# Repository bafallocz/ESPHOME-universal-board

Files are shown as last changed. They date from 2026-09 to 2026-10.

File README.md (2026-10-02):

# ESPHOME-universal-board

Modular, multi-purpose automation control boards designed around the **Seeed Studio XIAO** form-factor (ESP32-C3 / S3 / RP2040), tailored for **ESPHome**, **Home Assistant**, and standalone embedded automation projects.

The system consists of three hardware revisions/modules:
1. **Universal Board (Full Version)** – High-density I/O, mains-powered, precision analog/PWM expansion, gate-driven power MOSFETs, and relays.
2. **Universal Board (Light Version)** – Compact DC-powered board with direct logic-level SMD MOSFETs, relays, and inputs.
3. **Relay Expansion Board (Stackable)** – Dedicated 5-channel relay daughterboard controlled via the Full version's I2C PWM expander.

---

## Hardware Overview & Specifications

### 1. Board One: Full Version (Flagship)

Designed as a central automation node capable of direct 230 V mains operation, multi-channel high-current PWM control, mixed-signal ADC/DAC sensing, and galvanic isolation.

* **Core MCU:** Socket for Seeed Studio XIAO module (ESP32-C3, ESP32-S3, etc.).
* **Power Supply Options:**
  * **Mains AC Input:** Onboard **Hi-Link HLK-20M12** (20 W, 12 V / 1.66 A) isolated AC/DC power supply.
  * **Mains Protection:** 10D561K Metal Oxide Varistor (MOV) for surge and transient suppression.
  * **DC Input:** 2.1 mm DC Barrel Jack (`PJ-102AH`) for external 12 V DC supply.
  * **Step-Down:** Footprint for LM7805 LDO or pin-compatible high-efficiency DC-DC switching buck regulator (12 V to 5 V).
* **Power Outputs (4x High-Current PWM):**
  * **MOSFETs:** TO-220 footprint (tested with **IRL540N** / **IRFB4110PBF**).
  * **Gate Drivers:** Dual high-speed drivers (**TC4427** running at 12 V rail). Delivers up to 1.5 A peak gate drive current for fast switching transitions and minimal thermal loss during high-frequency PWM.
  * **Ratings:** Up to 60 V DC, 10 A burst / 5 A continuous per channel (dependent on PCB copper weight and heatsinking).
* **Analog & Precision I/O:**
  * **Analog Devices AD5593R** (12-bit, 8-channel configurable ADC / DAC / GPIO via I2C).
  * Onboard 2.5 V low-drift reference (`VREF`), filtered analog supplies, and dedicated 8-pin terminal/pin header.
* **Expanded PWM:**
  * **NXP PCA9685PW** (16-channel, 12-bit I2C PWM controller).
  * Channel `LED0` can be routed to high-current output/dimming, remaining channels (`EX_PWM1`–`EX_PWM15`) routed to stack header `JP1`.
* **Relays (2x Isolated):**
  * **Songle SRD-05VDC-SL-C** SPDT relays (rated 250 VAC / 10 A, 30 VDC / 10 A).
  * **Isolation & Drive:** Opto-isolated via **CPC1018N** 1-Form-A Solid State Relays (SSR) to isolate MCU logic from inductive switching spikes.
  * Flyback protection diodes on each coil.
* **Digital Inputs (2x Terminals):**
  * Dedicated screw terminals with 1k series current limiting.
  * **Nexperia PESD3V3L2BT** TVS/ESD diode array for surge/ESD protection on 3.3 V logic.
* **Expansion:** All unused XIAO GPIOs routed to standard 2.54 mm pin headers (`PHD1`, `PHD2`).

---

### 2. Board Two: Light Version

A low-profile, cost-optimized DC-powered board ideal for decentralized sub-nodes, LED strip dimming, and valve/motor switching.

* **Core MCU:** Seeed Studio XIAO module footprint.
* **Power Supply:**
  * DC Barrel Jack (`PJ-102AH`) feeding a dedicated pin-compatible DC-DC Step-Down module.
  * USB-C 5 V powering option with selectable `U_SEL` power routing jumper.
* **Power Outputs (3x SMD PWM):**
  * **MOSFETs:** **AO3400A** (N-channel, 30 V / 5.7 A).
  * Driven directly from MCU GPIOs.
  * Ideal for 12 V / 24 V LED strips (up to 3 A continuous per channel without forced cooling).
* **Relays (2x):**
  * 2x **SRD-05VDC-SL-C** driven via **CPC1018N** solid-state optical switches.
* **Digital Inputs (2x):**
  * Terminal block inputs with pull-ups/pull-downs for reed switches, dry contacts, or external buttons.
* **Expansion:** Unused pins broken out to side headers for I2C or SPI sensors.

---

### 3. Board Three: Expansion Board (Stackable)

An add-on hat designed to mount directly onto the **Full Version** via headers `PHD1`, `PHD2`, and `JP1`.

* **5x Additional Relays:** **SRD-05VDC-SL-C** (230 VAC / 10 A contact rating).
* **Control Bus:** Driven directly by the Full Board’s **PCA9685** PWM/GPIO expander (`EX_PWM1` through `EX_PWM5`).
* **Isolation:** Each relay coil is switched through an independent **CPC1018N** optical isolation relay.
* **Pass-through Routing:**
  * Leaves `EX_PWM6`–`EX_PWM15` available for additional servo or PWM peripherals.
  * Passes through AD5593R DAC/ADC lines and spare MCU GPIOs.

---

## Hardware Operating Limits & Safety Guidelines

> [!WARNING]
> **Mains Voltage Hazard:** The Full Version contains exposed 230 VAC tracks. Always install in an insulated DIN-rail or 3D-printed enclosure (**FR MATERIAL**). Maintain appropriate creepage and clearance distances between mains tracks and low-voltage logic.

* **Relay Contacts:** Rated for 10 A @ 250 VAC resistive load. For inductive loads (motors, pumps, contactors).
* **Full Board PWM Channels:** While the MOSFETs (IRFB4110 / IRL540N) have high silicon current ratings.
* **Light Board PWM Channels:** AO3400A is rated for 5.7 A peak; recommended continuous load per channel is **2.5 A to 3 A** without a copper heatsink pour.
* **Power Supply Headroom:** The HLK-20M12 provides up to 1.66 A at 12 V. When running multiple relays and external 12 V loads simultaneously, verify total DC power consumption remains under 20 W.

---

## AD5593R ESPHome Component

This repository includes a custom ESPHome component for the **Analog Devices AD5593R** (8-channel 12-bit configurable ADC / DAC / GPIO).

### How to Import into ESPHome

Add the `external_components` block to your YAML configuration:

#### Option A: Direct from GitHub
```yaml
external_components:
  - source: github://bafallocz/ESPHOME-universal-board
    components: [ ad5593r ]
```

#### Option B: Local Component (when compiling inside this repo)
```yaml
external_components:
  - source: components
    components: [ ad5593r ]
```

---

### AD5593R Configuration Guide

Any of the 8 pins (`0` to `7`) can be independently configured as an **ADC input**, **DAC output**, **Digital input (`binary_sensor`)**, or **Digital output (`switch`)**.

#### 1. Hub Definition
```yaml
ad5593r:
  - id: ad5593r_hub
    i2c_id: bus_a
    address: 0x10
    # reference_voltage: 2.5V  # Internal reference (default 2.5V)
    # gain_2x: true            # Default true -> Full range 0 to 5.0 V
```

#### 2. Analog Outputs (DAC) - Channels 0 to 7
Outputs range from `0.0` (0 V) to `1.0` (5.0 V):
```yaml
output:
  - platform: ad5593r
    ad5593r_id: ad5593r_hub
    channel: 0
    id: dac_out_0

  - platform: ad5593r
    ad5593r_id: ad5593r_hub
    channel: 1
    id: dac_out_1
```

Control DAC outputs using a Home Assistant template slider:
```yaml
number:
  - platform: template
    name: "DAC 0 Output"
    min_value: 0
    max_value: 1
    step: 0.01
    mode: slider
    set_action:
      - output.set_level:
          id: dac_out_0
          level: !lambda 'return x;'
```

#### 3. Analog Inputs (ADC) & Internal Temperature Sensor
Reports voltage values in **Volts (V)**:
```yaml
sensor:
  - platform: ad5593r
    ad5593r_id: ad5593r_hub
    channel: 2
    name: "AD5593R Analog Input 2"
    update_interval: 1s

  - platform: ad5593r
    ad5593r_id: ad5593r_hub
    channel: 3
    name: "AD5593R Analog Input 3"
    update_interval: 1s

  # Chip Internal Temperature Sensor (°C)
  - platform: ad5593r
    ad5593r_id: ad5593r_hub
    channel: temperature
    name: "AD5593R Internal Temperature"
    update_interval: 10s
```

#### 4. Digital Inputs (`binary_sensor`)
Reads logic state from pins (with optional 85 kΩ internal pull-down):
```yaml
binary_sensor:
  - platform: ad5593r
    ad5593r_id: ad5593r_hub
    channel: 4
    name: "AD5593R Digital Input 4"
    pulldown: true
```

#### 5. Digital Outputs (`switch`)
Controls digital output logic high/low on pins:
```yaml
switch:
  - platform: ad5593r
    ad5593r_id: ad5593r_hub
    channel: 5
    name: "AD5593R Digital Output 5"
```

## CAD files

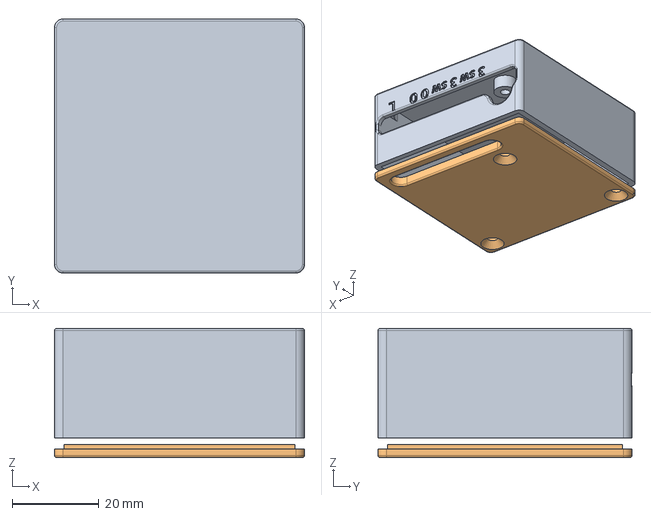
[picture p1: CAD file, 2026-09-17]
LIGH VERSION/esp_home_light_housing.step
57.7 x 58.7 x 29.8 mm

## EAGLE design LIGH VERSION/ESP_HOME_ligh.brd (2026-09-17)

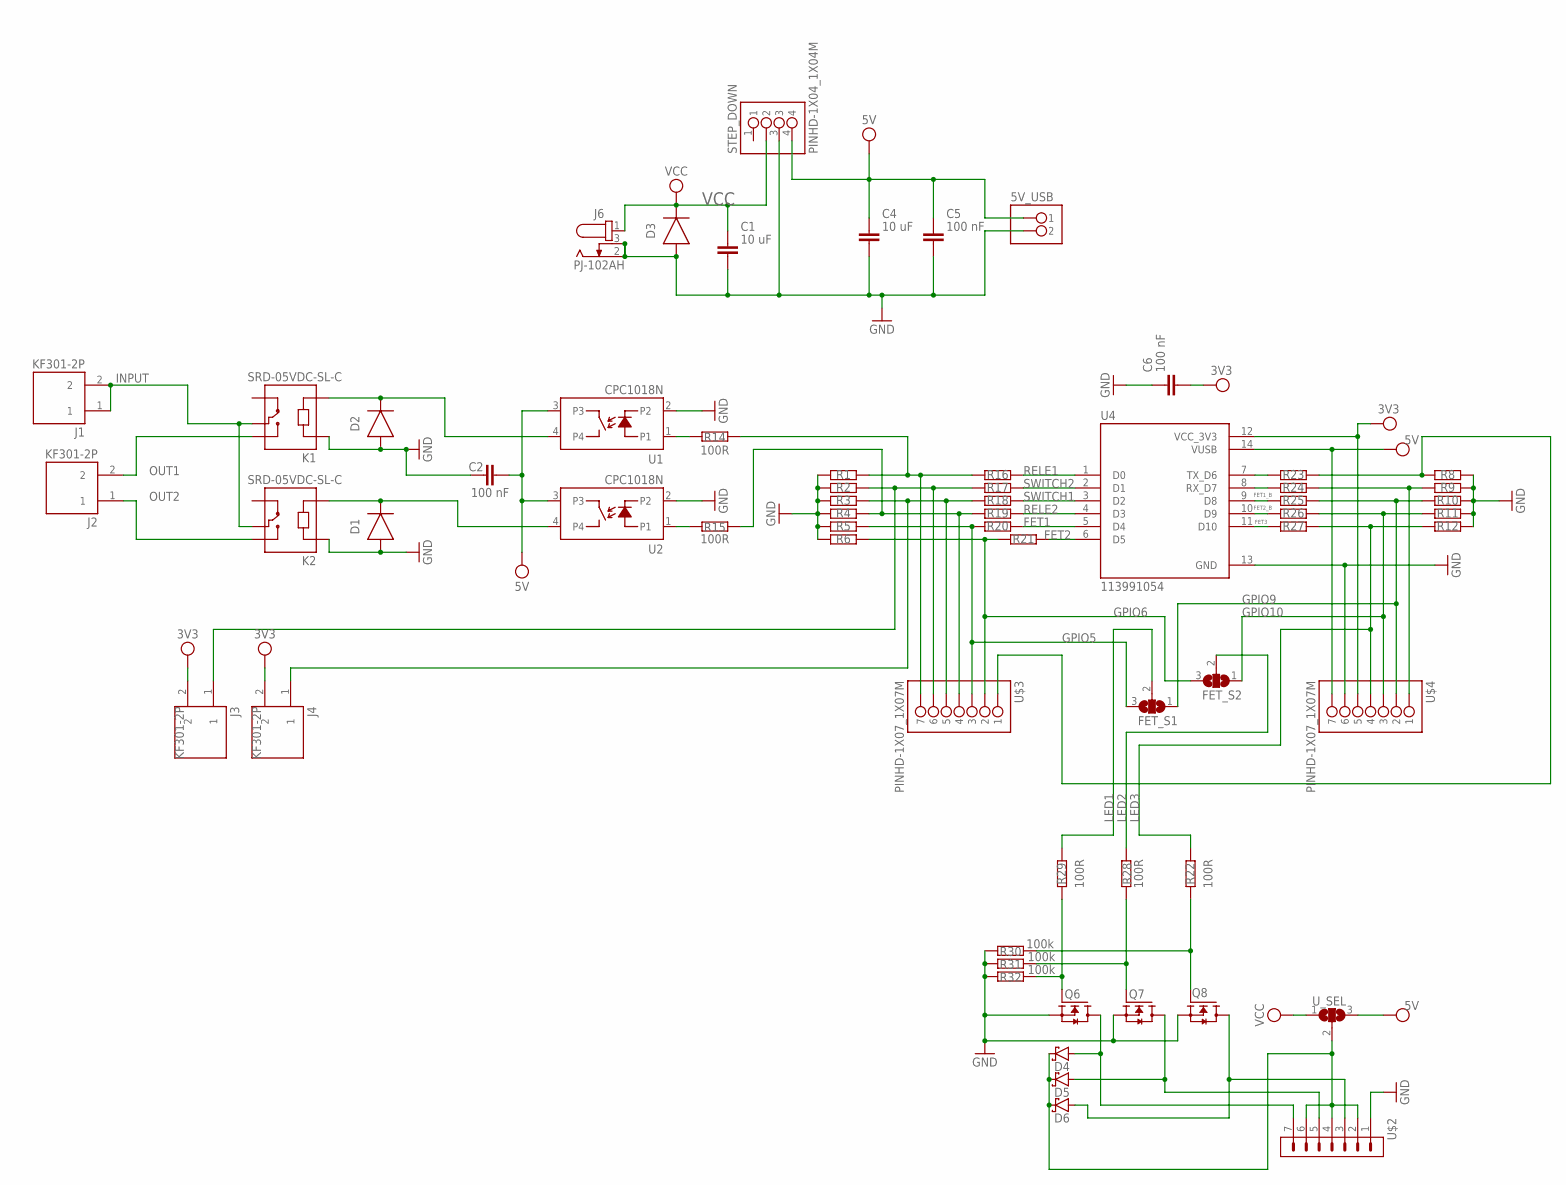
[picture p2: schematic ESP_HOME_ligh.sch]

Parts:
5V_USB: PINHD-1X02_1X02M; 1X02
C1, C4: 10 uF; CAPC2012X110
C2, C5, C6: 100 nF; CAPC2012X110
D1, D2, D3: DIODEDIODE-AXIAL; DIODE-AXIAL
D4, D5, D6: SCHOTTKY_MBR0520LT1GDO-219; SODFL3718X115
FET_S1, FET_S2: SJ2W; SJ_2
J1, J2, J3, J4: KF301-2P; HANDSON_KF301-2P
J6: PJ-102AH
K1, K2: SRD-05VDC-SL-C; RELAY_SRD-05VDC-SL-C
Q6, Q7, Q8: AO3400A; SOT95P280X125-3N
R1, R2, R3, R4, R5, R6, R8, R9, R10, R11, R12, R16, R17, R18, R19, R20, R21, R23, R24, R25, R26, R27: R_CHIP-1206(3216-METRIC); RESC3216X70
R14, R15, R22, R28, R29: 100R; RESC3216X70
R30, R31, R32: 100k; RESC3216X70
STEP_DOWN: PINHD-1X04_1X04M; 1X04
U1, U2: CPC1018N; CLARE_SO4
U4: 113991054; MODULE_113991054
U$2: PINHD-1X7; 1X07
U$3, U$4: PINHD-1X07_1X07M; 1X07
U_SEL: SJ2W; SJ_2

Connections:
3V3: C6.2, J3.2, J4.2, U4.12 (VCC_3V3), U$4.5
5V: 5V_USB.1, C2.2, C4.1, C5.1, STEP_DOWN.4, U1.3, U2.3, U4.14 (VUSB), U$4.7, U_SEL.3
FET1: R20.2, U4.5 (D4)
FET1_B: R25.1, U4.9 (D8)
FET2: R21.2, U4.6 (D5)
FET2_B: R26.1, U4.10 (D9)
FET3: R27.1, U4.11 (D10)
GND: 5V_USB.2, C1.2, C2.1, C4.2, C5.2, C6.1, D1.1 (A), D2.1 (A), D3.1 (A), J6.2, J6.3, K1.A1, K2.A1, Q6.2 (S), Q7.2 (S), Q8.2 (S), R1.1, R2.1, R3.1, R4.1, R5.1, R6.1, R8.2, R9.2, R10.2, R11.2, R12.2, R30.2, R31.2, R32.2, STEP_DOWN.3, U1.2, U2.2, U4.13 (GND), U$2.1, U$4.6
GPIO5: FET_S1.3, R5.2, R20.1, U$3.3
GPIO6: FET_S2.3, R6.2, R21.1, U$3.2
GPIO9: FET_S1.1, R10.1, R25.2, U$4.2
GPIO10: FET_S2.1, R11.1, R26.2, U$4.3
INPUT: J1.1, J1.2, K1.COM, K2.COM
LED1: FET_S1.2, R29.2
LED2: FET_S2.2, R28.1
LED3: R12.1, R22.2, R27.2, U$4.4
unnamed: R14.2, U1.1
unnamed: D4.2 (A), Q6.3 (D), U$2.7
unnamed: R23.1, U4.7 (TX_D6)
unnamed: R24.1, U4.8 (RX_D7)
unnamed: Q6.1 (G), R29.1, R32.1
unnamed: Q7.1 (G), R28.2, R31.1
unnamed: Q8.1 (G), R22.1, R30.1
unnamed: R15.2, U2.1
unnamed: D1.2 (C), K2.A2, U2.4
unnamed: D2.2 (C), K1.A2, U1.4
unnamed: R9.1, R24.2, U$4.1
unnamed: R8.1, R23.2, U$3.1
unnamed: R4.2, R15.1, R19.1, U$3.4
unnamed: D4.1 (C), D5.1 (C), D6.1 (C), U$2.2, U$2.4, U$2.6, U_SEL.2
unnamed: D5.2 (A), Q7.3 (D), U$2.5
unnamed: D6.2 (A), Q8.3 (D), U$2.3
unnamed: R1.2, R14.1, R16.1, U$3.7
OUT1: J2.2, K1.NO
OUT2: J2.1, K2.NO
RELE1: R16.2, U4.1 (D0)
RELE2: R19.2, U4.4 (D3)
SW1: J3.1, R2.2, R17.1, U$3.6
SW2: J4.1, R3.2, R18.1, U$3.5
SWITCH1: R18.2, U4.3 (D2)
SWITCH2: R17.2, U4.2 (D1)
VCC: C1.1, D3.2 (C), J6.1, STEP_DOWN.2, U_SEL.1

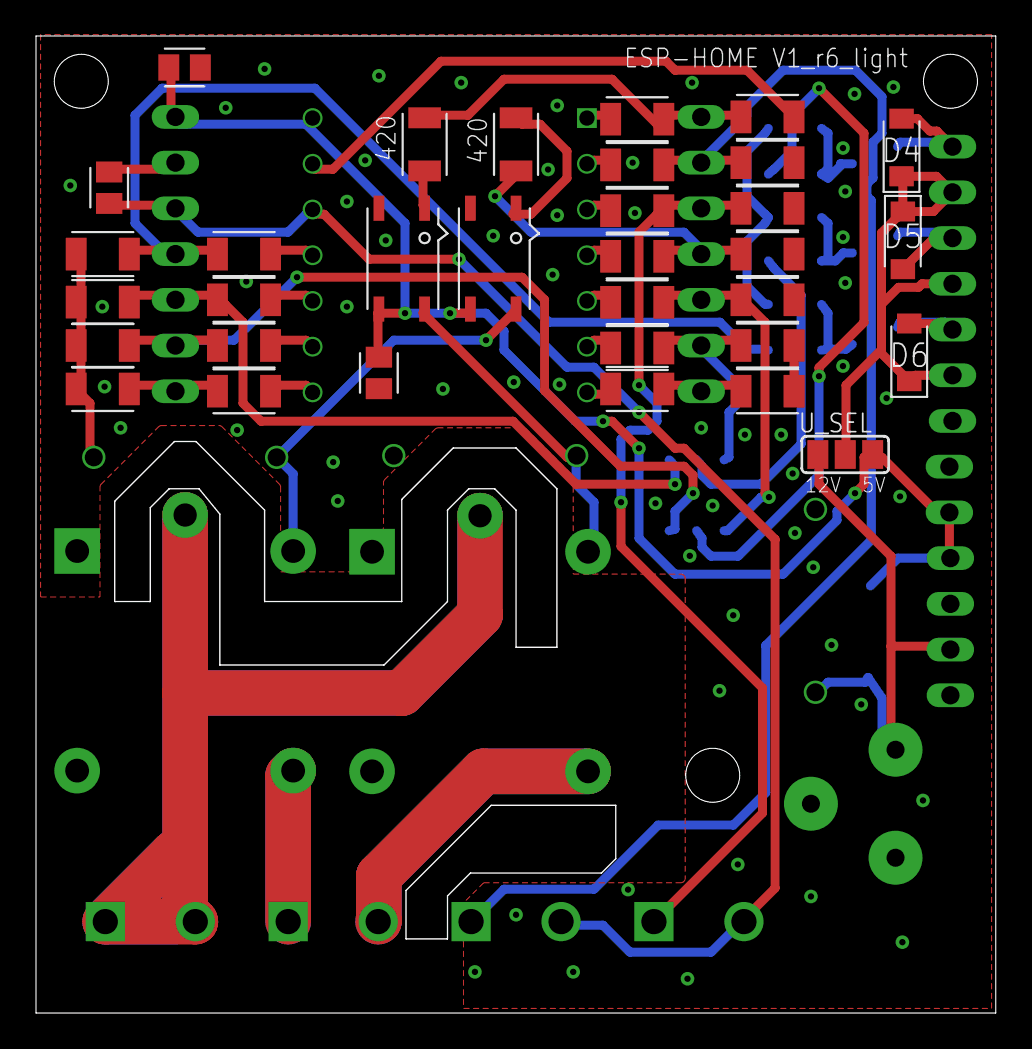
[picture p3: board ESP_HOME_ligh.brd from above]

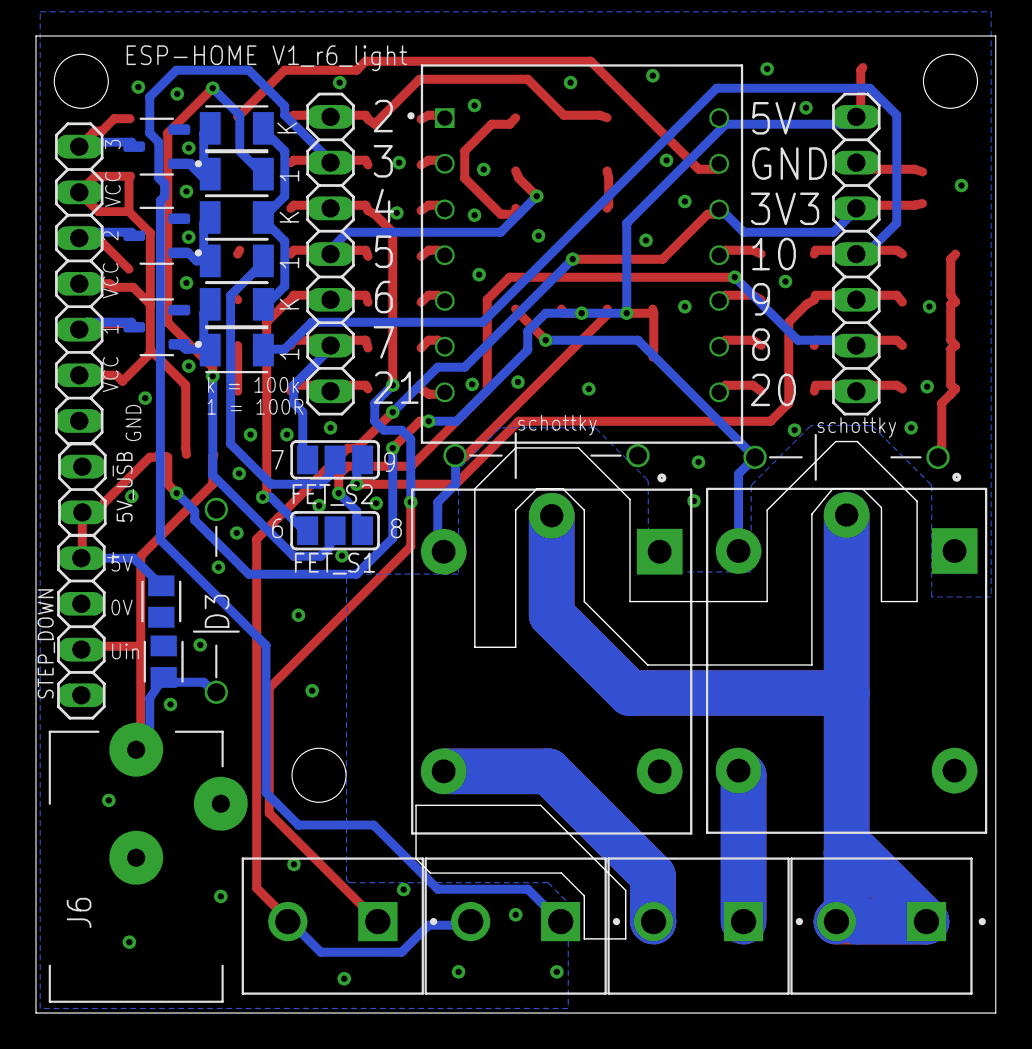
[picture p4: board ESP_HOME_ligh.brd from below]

Board: 2 copper layers, 53.3 x 54.3 mm, 62 parts (29 on the bottom side), 42 nets.

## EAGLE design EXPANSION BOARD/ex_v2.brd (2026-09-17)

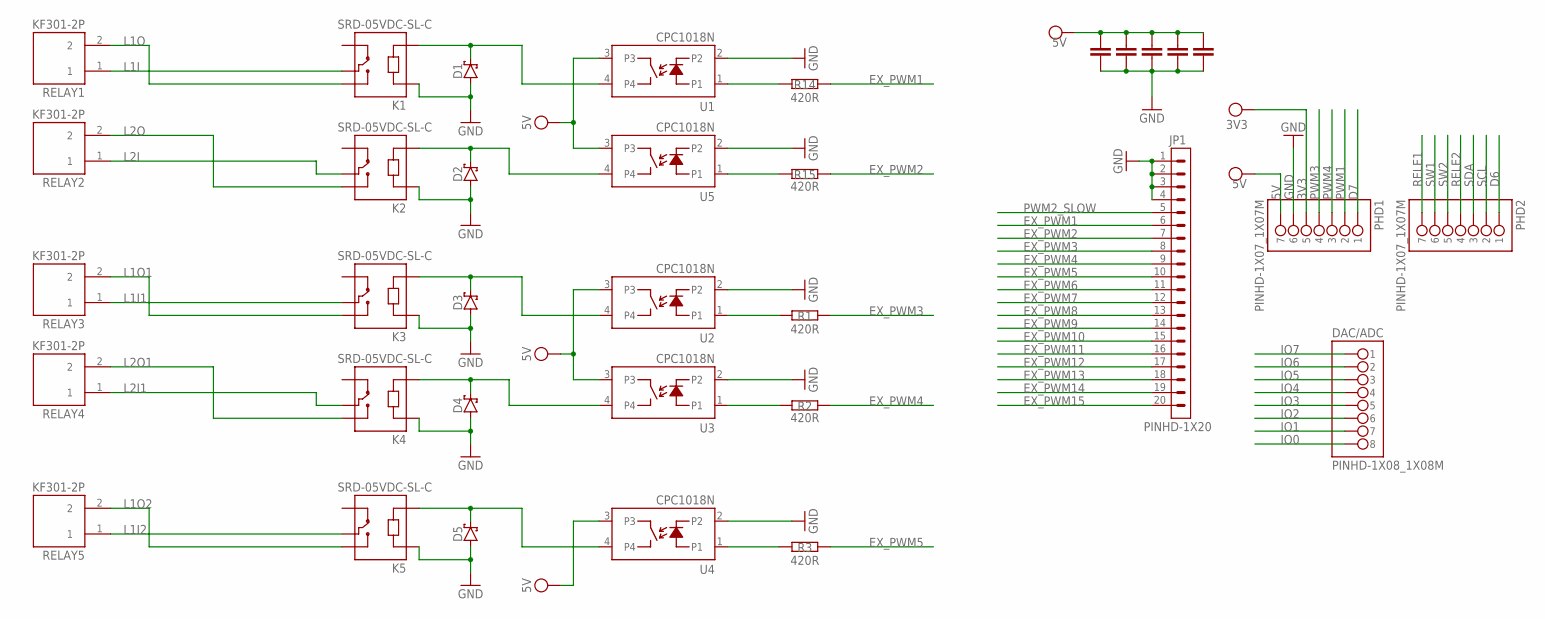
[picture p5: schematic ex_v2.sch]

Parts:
C1, C2, C3, C6, C8: 10uF; CAPC2012X110
D1, D2, D3, D4, D5: SCHOTTKY_MBR0520LT1GDO-219; SODFL3718X115
DAC/ADC: PINHD-1X08_1X08M; 1X08
JP1: PINHD-1X20; 1X20
K1, K2, K3, K4, K5: SRD-05VDC-SL-C; RELAY_SRD-05VDC-SL-C
PHD1, PHD2: PINHD-1X07_1X07M; 1X07
R1, R2, R3, R14, R15: 420R; RESC1608X60
RELAY1, RELAY2, RELAY3, RELAY4, RELAY5: KF301-2P; HANDSON_KF301-2P
U1, U2, U3, U4, U5: CPC1018N; CLARE_SO4

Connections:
3V3: PHD1.5
5V: C1.1, C2.1, C3.1, C6.1, C8.1, PHD1.7, U1.3, U2.3, U3.3, U4.3, U5.3
D6: PHD2.1
D7: PHD1.1
EX_PWM1: JP1.6, R14.1
EX_PWM2: JP1.7, R15.1
EX_PWM3: JP1.8, R1.1
EX_PWM4: JP1.9, R2.1
EX_PWM5: JP1.10, R3.1
EX_PWM6: JP1.11
EX_PWM7: JP1.12
EX_PWM8: JP1.13
EX_PWM9: JP1.14
EX_PWM10: JP1.15
EX_PWM11: JP1.16
EX_PWM12: JP1.17
EX_PWM13: JP1.18
EX_PWM14: JP1.19
EX_PWM15: JP1.20
GND: C1.2, C2.2, C3.2, C6.2, C8.2, D1.2 (A), D2.2 (A), D3.2 (A), D4.2 (A), D5.2 (A), JP1.1, JP1.2, JP1.3, JP1.4, K1.A1, K2.A1, K3.A1, K4.A1, K5.A1, PHD1.6, U1.2, U2.2, U3.2, U4.2, U5.2
IO0: DAC/ADC.8
IO1: DAC/ADC.7
IO2: DAC/ADC.6
IO3: DAC/ADC.5
IO4: DAC/ADC.4
IO5: DAC/ADC.3
IO6: DAC/ADC.2
IO7: DAC/ADC.1
L1I: K1.COM, RELAY1.1
L1I1: K3.COM, RELAY3.1
L1I2: K5.COM, RELAY5.1
L1O: K1.NO, RELAY1.2
L1O1: K3.NO, RELAY3.2
L1O2: K5.NO, RELAY5.2
L2I: K2.COM, RELAY2.1
L2I1: K4.COM, RELAY4.1
L2O: K2.NO, RELAY2.2
L2O1: K4.NO, RELAY4.2
unnamed: R1.2, U2.1
unnamed: R2.2, U3.1
unnamed: D4.1 (C), K4.A2, U3.4
unnamed: D3.1 (C), K3.A2, U2.4
unnamed: D2.1 (C), K2.A2, U5.4
unnamed: D1.1 (C), K1.A2, U1.4
unnamed: R3.2, U4.1
unnamed: D5.1 (C), K5.A2, U4.4
unnamed: R14.2, U1.1
unnamed: R15.2, U5.1
PWM1: PHD1.2
PWM2_SLOW: JP1.5
PWM3: PHD1.4
PWM4: PHD1.3
RELE1: PHD2.7
RELE2: PHD2.4
SCL: PHD2.2
SDA: PHD2.3
SW1: PHD2.6
SW2: PHD2.5

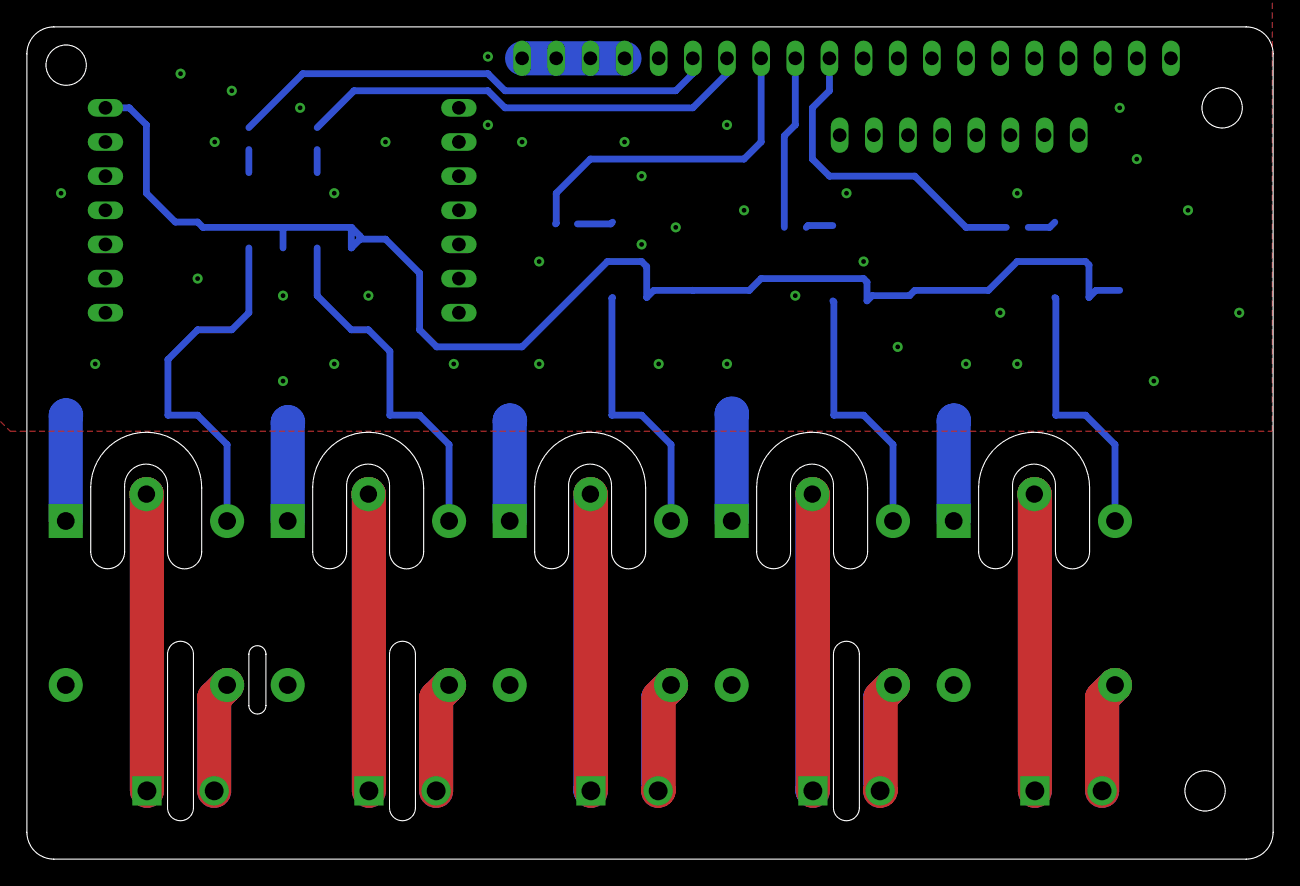
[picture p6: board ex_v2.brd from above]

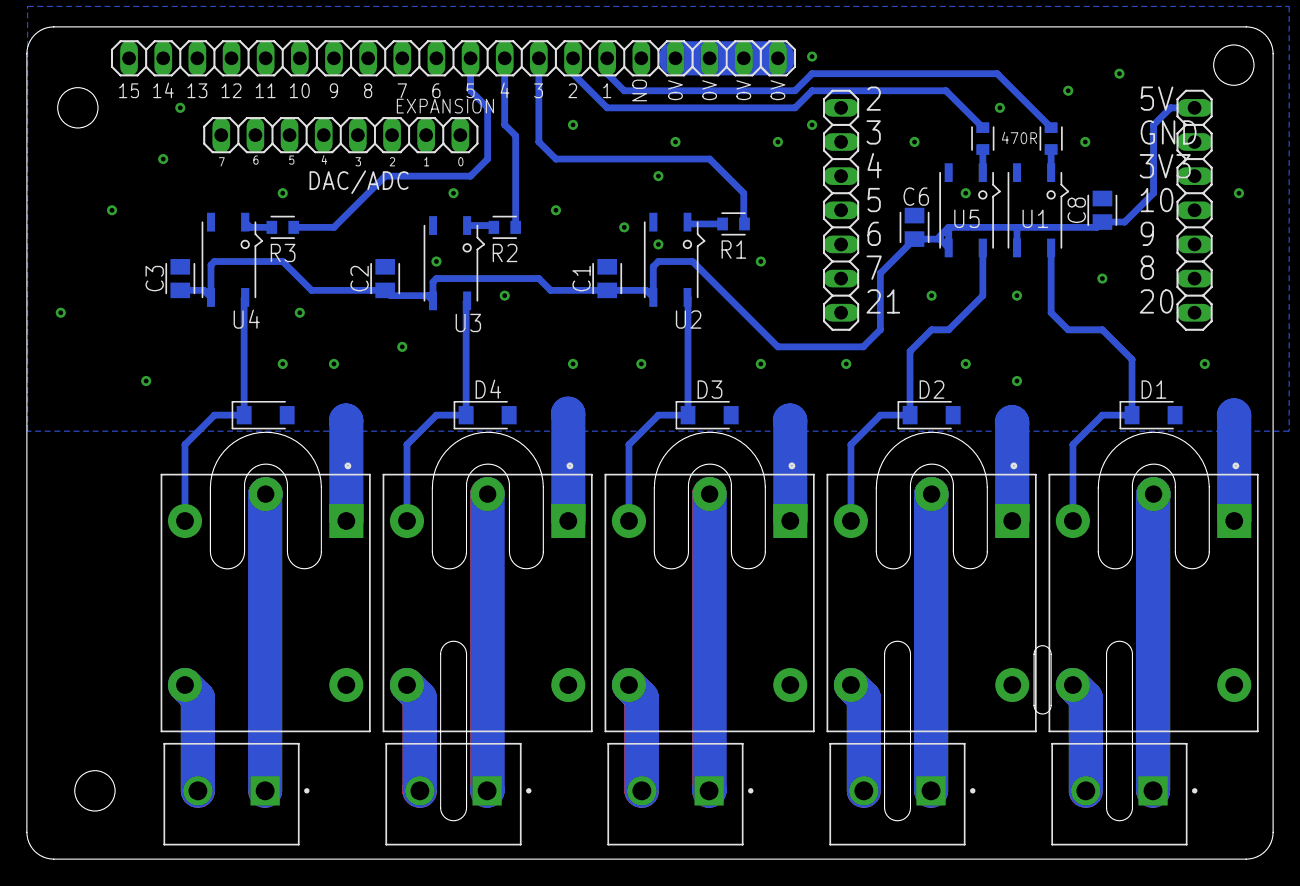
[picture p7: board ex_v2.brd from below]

Board: 2 copper layers, 92.7 x 61.9 mm, 34 parts (34 on the bottom side), 27 nets.

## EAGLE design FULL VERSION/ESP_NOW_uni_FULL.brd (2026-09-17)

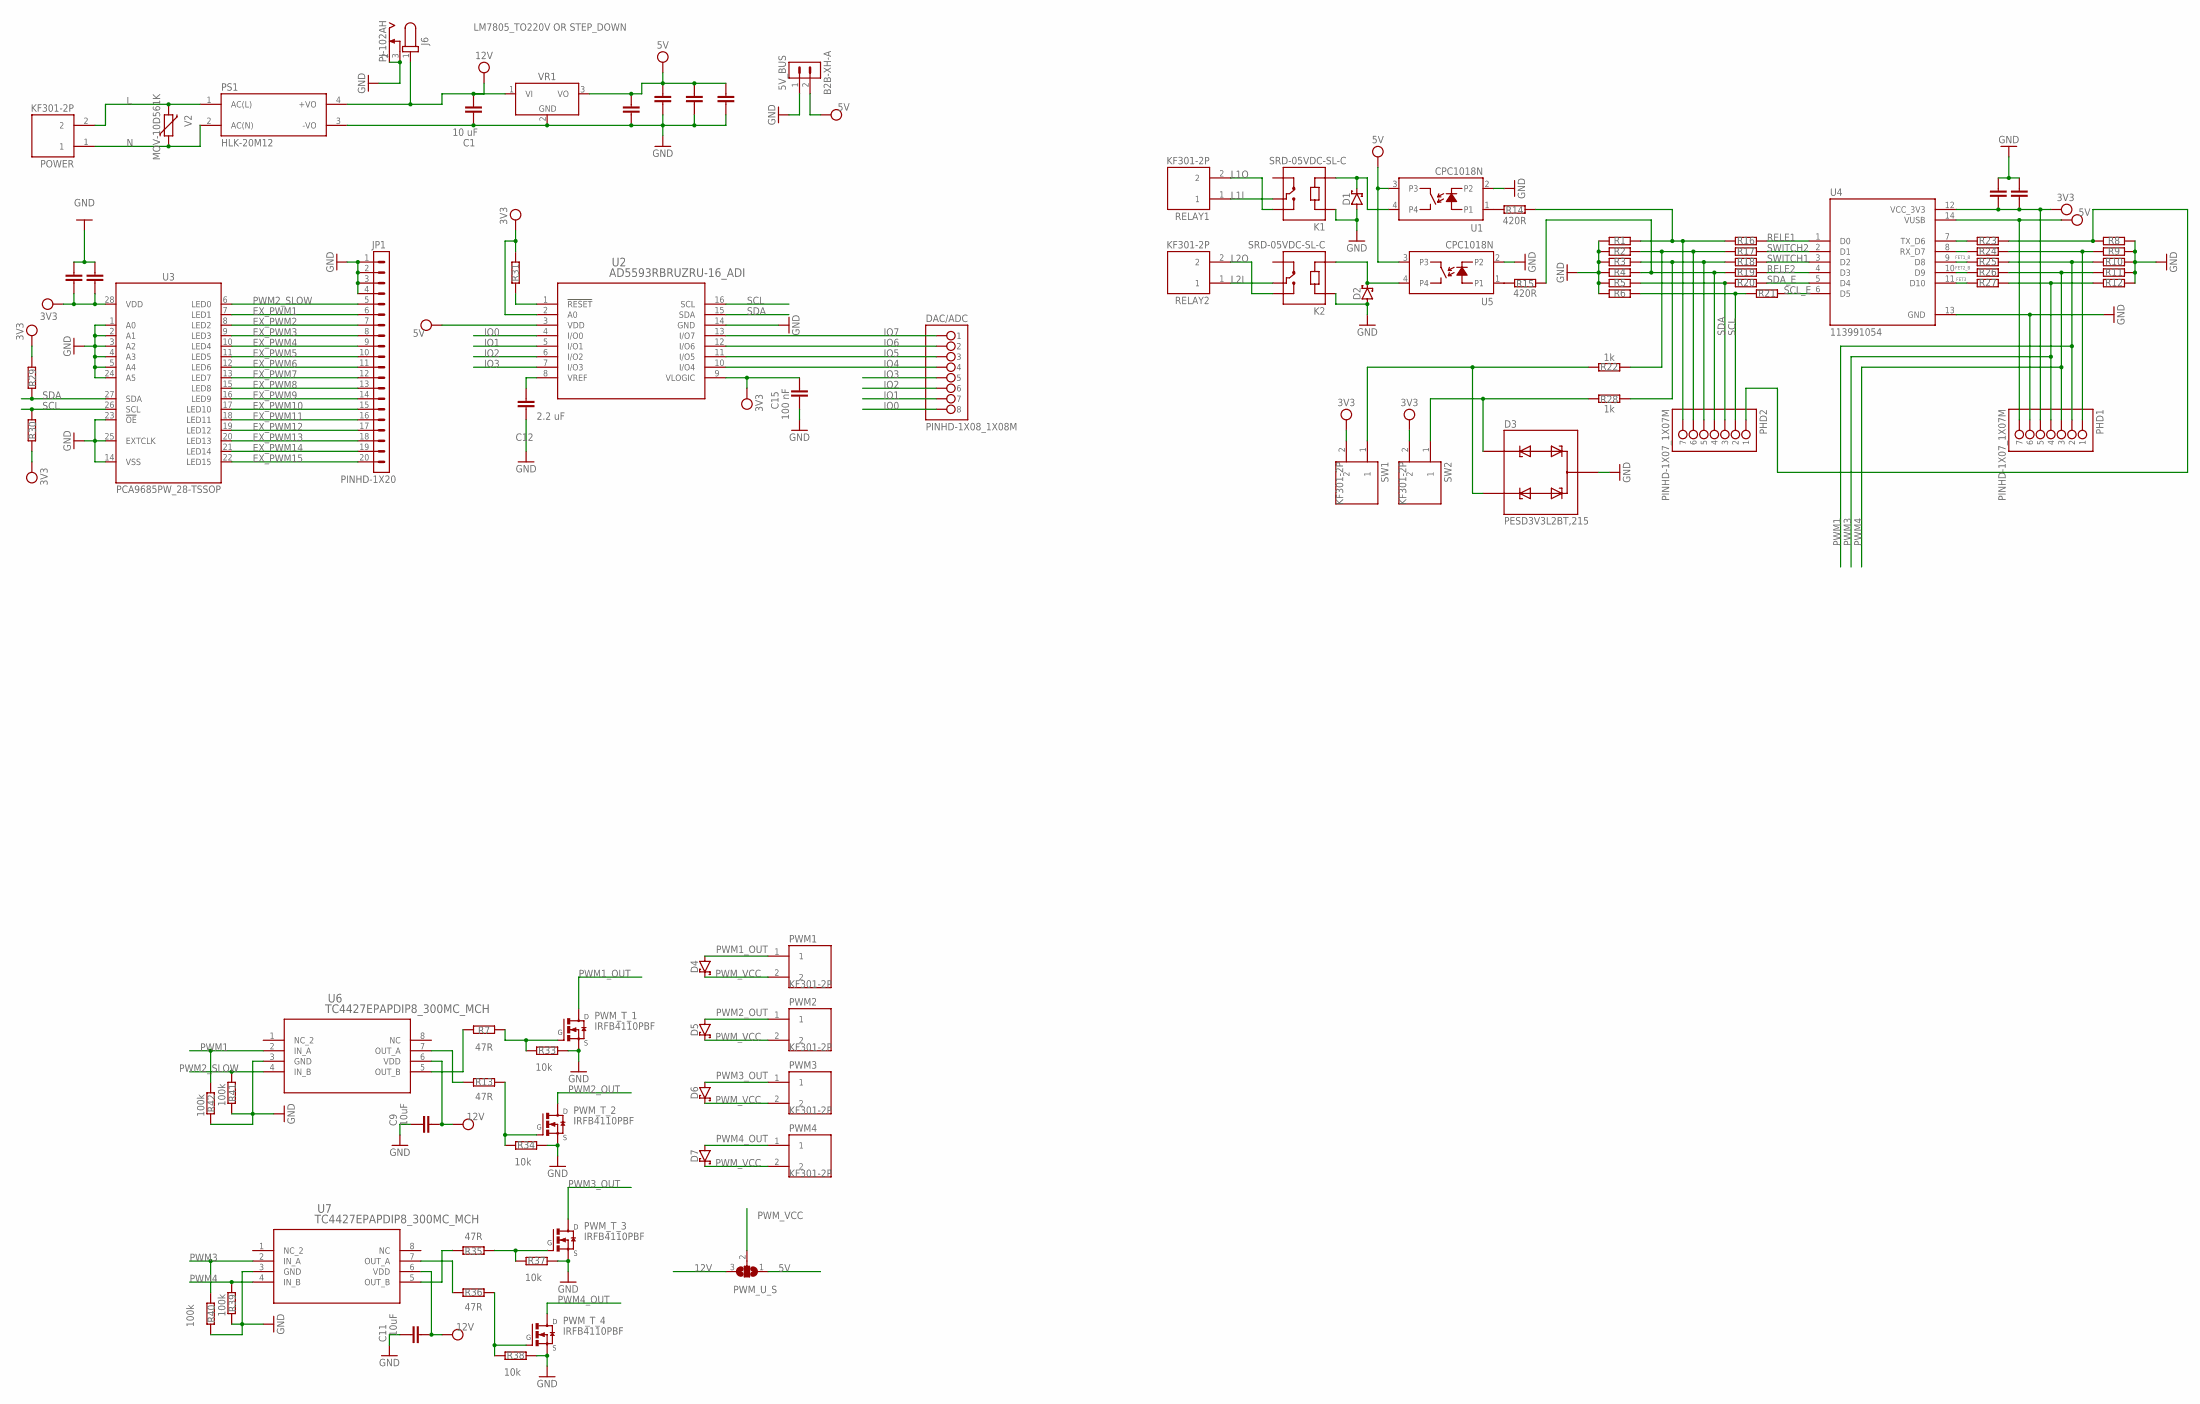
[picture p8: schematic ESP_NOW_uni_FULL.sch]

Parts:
5V_BUS: B2B-XH-A
C1: 10 uF; CAPC2012X110
C2: 0.1uF; CAPC2012X110
C3, C4, C5, C6, C7, C8, C9, C10, C11: 10uF; CAPC2012X110
C12: 2.2 uF; CAPC2012X110
C15: 100 nF; CAPC2012X110
D1, D2, D4, D5, D6, D7: SCHOTTKY_MBR0520LT1GDO-219; SODFL3718X115
D3: PESD3V3L2BT,215; SOT95P230X110-3N
DAC/ADC: PINHD-1X08_1X08M; 1X08
J6: PJ-102AH
JP1: PINHD-1X20; 1X20
K1, K2: SRD-05VDC-SL-C; RELAY_SRD-05VDC-SL-C
PHD1, PHD2: PINHD-1X07_1X07M; 1X07
POWER: KF301-2P; HANDSON_KF301-2P
PS1: HLK-20M12; CONV_HLK-20M12
PWM1, PWM2, PWM3, PWM4: KF301-2P; HANDSON_KF301-2P
PWM_T_1, PWM_T_2, PWM_T_3, PWM_T_4: IRFB4110PBF; TO220V
PWM_U_S: SJ2W; SJ_2
R1, R2, R3, R4, R5, R6, R8, R9, R10, R11, R12, R16, R17, R18, R19, R20, R21, R23, R24, R25, R26, R27, R29, R30, R31: R_CHIP-0603(1608-METRIC); RESC1608X60
R7, R13, R35, R36: 47R; RESC1608X60
R14, R15: 420R; RESC1608X60
R22, R28: 1k; RESC1608X60
R33, R34, R37, R38: 10k; RESC1608X60
R39, R40, R41, R42: 100k; RESC1608X60
RELAY1, RELAY2: KF301-2P; HANDSON_KF301-2P
SW1, SW2: KF301-2P; HANDSON_KF301-2P
U1, U5: CPC1018N; CLARE_SO4
U2: AD5593RBRUZRU-16_ADI; RU-16_ADI
U3: PCA9685PW_28-TSSOP; SOP65P640X110-28
U4: 113991054; MODULE_113991054
U6, U7: TC4427EPAPDIP8_300MC_MCH; PDIP8_300MC_MCH
V2: MOV-10D561K; MOV-10D561
VR1: LM7805_TO220V OR STEP_DOWN; TO220V

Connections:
3V3: C6.2, C7.2, C8.2, C10.2, C15.1, PHD1.5, R29.1, R30.2, R31.2, SW1.2, SW2.2, U2.2 (A0), U2.9 (VLOGIC), U3.28 (VDD), U4.12 (VCC_3V3)
5V: 5V_BUS.2, C2.1, C3.1, C4.1, C5.1, PHD1.7, PWM_U_S.1, U1.3, U2.3 (VDD), U4.14 (VUSB), U5.3, VR1.3 (VO)
12V: C1.1, C9.1, C11.1, J6.1, PS1.4 (+VO), PWM_U_S.3, U6.6 (VDD), U7.6 (VDD), VR1.1 (VI)
EX_PWM1: JP1.6, U3.7 (LED1)
EX_PWM2: JP1.7, U3.8 (LED2)
EX_PWM3: JP1.8, U3.9 (LED3)
EX_PWM4: JP1.9, U3.10 (LED4)
EX_PWM5: JP1.10, U3.11 (LED5)
EX_PWM6: JP1.11, U3.12 (LED6)
EX_PWM7: JP1.12, U3.13 (LED7)
EX_PWM8: JP1.13, U3.15 (LED8)
EX_PWM9: JP1.14, U3.16 (LED9)
EX_PWM10: JP1.15, U3.17 (LED10)
EX_PWM11: JP1.16, U3.18 (LED11)
EX_PWM12: JP1.17, U3.19 (LED12)
EX_PWM13: JP1.18, U3.20 (LED13)
EX_PWM14: JP1.19, U3.21 (LED14)
EX_PWM15: JP1.20, U3.22 (LED15)
FET1_B: R25.1, U4.9 (D8)
FET2_B: R26.1, U4.10 (D9)
FET3: R27.1, U4.11 (D10)
GND: 5V_BUS.1, C1.2, C2.2, C3.2, C4.2, C5.2, C6.1, C7.1, C8.1, C9.2, C10.1, C11.2, C12.2, C15.2, D1.2 (A), D2.2 (A), D3.3 (CC), J6.2, J6.3, JP1.1, JP1.2, JP1.3, JP1.4, K1.A1, K2.A1, PHD1.6, PS1.3 (-VO), PWM_T_1.3 (S), PWM_T_2.3 (S), PWM_T_3.3 (S), PWM_T_4.3 (S), R1.1, R2.1, R3.1, R4.1, R5.1, R6.1, R8.2, R9.2, R10.2, R11.2, R12.2, R33.2, R34.2, R37.2, R38.2, R39.2, R40.2, R41.2, R42.2, U1.2, U2.14 (GND), U3.1 (A0), U3.2 (A1), U3.3 (A2), U3.4 (A3), U3.5 (A4), U3.14 (VSS), U3.23 (!OE), U3.24 (A5), U3.25 (EXTCLK), U4.13 (GND), U5.2, U6.3 (GND), U7.3 (GND), VR1.2 (GND)
IO0: DAC/ADC.8, U2.4 (I/O0)
IO1: DAC/ADC.7, U2.5 (I/O1)
IO2: DAC/ADC.6, U2.6 (I/O2)
IO3: DAC/ADC.5, U2.7 (I/O3)
IO4: DAC/ADC.4, U2.10 (I/O4)
IO5: DAC/ADC.3, U2.11 (I/O5)
IO6: DAC/ADC.2, U2.12 (I/O6)
IO7: DAC/ADC.1, U2.13 (I/O7)
L: POWER.2, PS1.1 (AC(L)), V2.2
L1I: K1.COM, RELAY1.1
L1O: K1.NO, RELAY1.2
L2I: K2.COM, RELAY2.1
L2O: K2.NO, RELAY2.2
N: POWER.1, PS1.2 (AC(N)), V2.1
unnamed: PWM_T_1.1 (G), R7.1, R33.1
unnamed: D3.2 (K2), R22.1, SW1.1
unnamed: R23.1, U4.7 (TX_D6)
unnamed: R24.1, U4.8 (RX_D7)
unnamed: D3.1 (K1), R28.2, SW2.1
unnamed: C12.1, U2.8 (VREF)
unnamed: D2.1 (C), K2.A2, U5.4
unnamed: D1.1 (C), K1.A2, U1.4
unnamed: R31.1, U2.1 (!RESET)
unnamed: PWM_T_2.1 (G), R13.2, R34.1
unnamed: PWM_T_3.1 (G), R35.1, R37.1
unnamed: PHD1.1, R9.1, R24.2
unnamed: PHD2.1, R8.1, R23.2
unnamed: PWM_T_4.1 (G), R36.2, R38.1
unnamed: PHD2.4, R4.2, R15.1, R19.1
unnamed: R7.2, U6.5 (OUT_B)
unnamed: R14.2, U1.1
unnamed: R15.2, U5.1
unnamed: R13.1, U6.7 (OUT_A)
unnamed: R36.1, U7.7 (OUT_A)
unnamed: R35.2, U7.5 (OUT_B)
unnamed: PHD2.7, R1.2, R14.1, R16.1
PWM1: PHD1.2, R10.1, R25.2, R42.1, U6.2 (IN_A)
PWM1_OUT: D4.2 (A), PWM1.1, PWM_T_1.2 (D)
PWM2_OUT: D5.2 (A), PWM2.1, PWM_T_2.2 (D)
PWM2_SLOW: JP1.5, R41.1, U3.6 (LED0), U6.4 (IN_B)
PWM3: PHD1.4, R12.1, R27.2, R40.1, U7.2 (IN_A)
PWM3_OUT: D6.2 (A), PWM3.1, PWM_T_3.2 (D)
PWM4: PHD1.3, R11.1, R26.2, R39.1, U7.4 (IN_B)
PWM4_OUT: D7.2 (A), PWM4.1, PWM_T_4.2 (D)
PWM_VCC: D4.1 (C), D5.1 (C), D6.1 (C), D7.1 (C), PWM1.2, PWM2.2, PWM3.2, PWM4.2, PWM_U_S.2
RELE1: R16.2, U4.1 (D0)
RELE2: R19.2, U4.4 (D3)
SCL: PHD2.2, R6.2, R21.1, R30.1, U2.16 (SCL), U3.26 (SCL)
SCL_E: R21.2, U4.6 (D5)
SDA: PHD2.3, R5.2, R20.1, R29.2, U2.15 (SDA), U3.27 (SDA)
SDA_E: R20.2, U4.5 (D4)
SW1: PHD2.6, R2.2, R17.1, R22.2
SW2: PHD2.5, R3.2, R18.1, R28.1
SWITCH1: R18.2, U4.3 (D2)
SWITCH2: R17.2, U4.2 (D1)

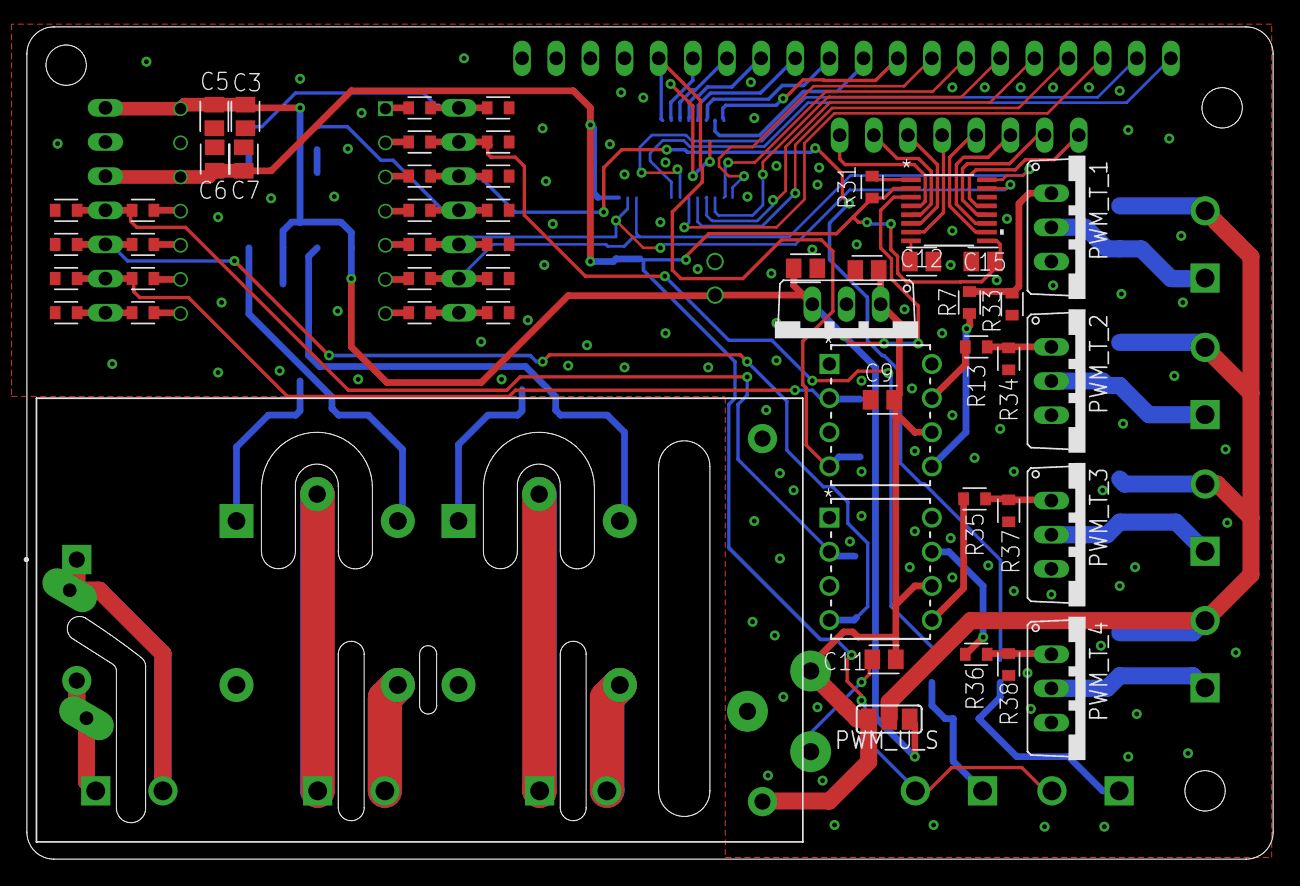
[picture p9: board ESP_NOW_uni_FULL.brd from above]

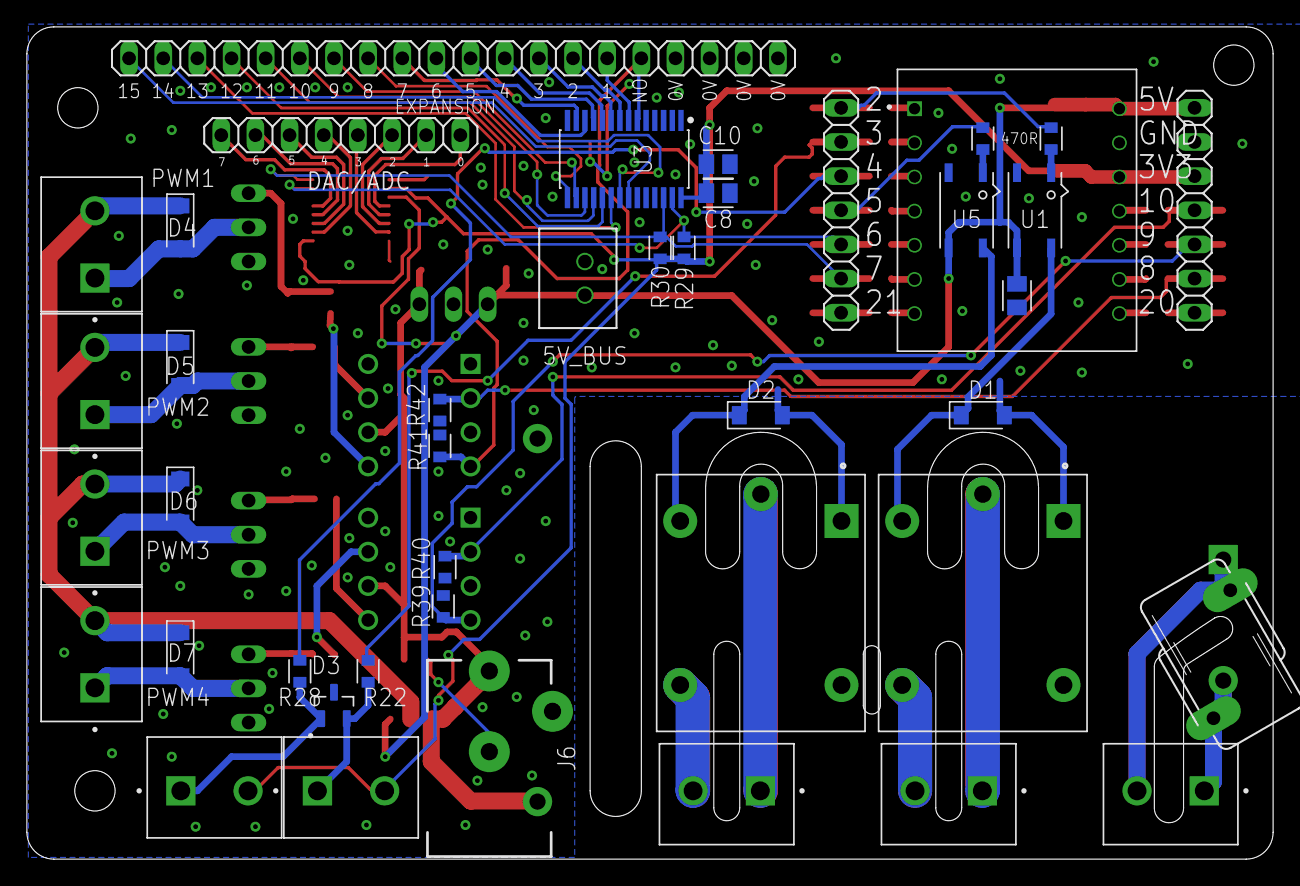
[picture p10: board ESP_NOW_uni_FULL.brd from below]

Board: 2 copper layers, 92.7 x 61.9 mm, 93 parts (42 on the bottom side), 77 nets.

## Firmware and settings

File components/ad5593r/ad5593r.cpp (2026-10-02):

#include "ad5593r.h"
#include "esphome/core/log.h"
#include <cmath>
#include <algorithm>

namespace esphome {
namespace ad5593r {

static const char *const TAG = "ad5593r";

// AD5593R Control Registers (Mode 0000)
static const uint8_t AD5593R_REG_NOP             = 0x00;
static const uint8_t AD5593R_REG_ADC_SEQ         = 0x02;
static const uint8_t AD5593R_REG_GEN_CTRL        = 0x03;
static const uint8_t AD5593R_REG_ADC_CONFIG      = 0x04;
static const uint8_t AD5593R_REG_DAC_CONFIG      = 0x05;
static const uint8_t AD5593R_REG_PULLDOWN        = 0x06;
static const uint8_t AD5593R_REG_LDAC_MODE       = 0x07;
static const uint8_t AD5593R_REG_GPIO_OUT_CONFIG = 0x08;
static const uint8_t AD5593R_REG_GPIO_OUT_DATA   = 0x09;
static const uint8_t AD5593R_REG_GPIO_IN_CONFIG  = 0x0A;
static const uint8_t AD5593R_REG_POWER_REF_CTRL  = 0x0B;
static const uint8_t AD5593R_REG_OPEN_DRAIN      = 0x0C;
static const uint8_t AD5593R_REG_THREE_STATE     = 0x0D;
static const uint8_t AD5593R_REG_SW_RESET        = 0x0F;

// Direct Operation Commands
static const uint8_t AD5593R_CMD_DAC_WRITE       = 0x10;
static const uint8_t AD5593R_CMD_ADC_READ        = 0x40;
static const uint8_t AD5593R_CMD_GPIO_READ       = 0x60;

#ifdef USE_OUTPUT
void AD5593RChannel::write_state(float state) {
  this->parent_->write_dac(this->channel_, state);
}
#endif

#ifdef USE_SENSOR
void AD5593RSensor::update() {
  if (this->parent_->is_failed()) {
    return;
  }

  if (this->channel_ == 8) {
    float temp_c;
    if (this->parent_->read_temperature(temp_c)) {
      this->publish_state(temp_c);
    } else {
      this->status_set_warning();
    }
  } else {
    float voltage;
    if (this->parent_->read_adc_voltage(this->channel_, voltage)) {
      this->publish_state(voltage);
    } else {
      this->status_set_warning();
    }
  }
}
#endif

#ifdef USE_BINARY_SENSOR
// AD5593RBinarySensor constructor is defined inline in ad5593r.h
#endif

#ifdef USE_SWITCH
void AD5593RSwitch::write_state(bool state) {
  if (this->parent_->write_gpio(this->channel_, state)) {
    this->publish_state(state);
  }
}
#endif

bool AD5593RComponent::write_reg_16(uint8_t reg, uint16_t value) {
  uint8_t data[2] = {static_cast<uint8_t>(value >> 8), static_cast<uint8_t>(value & 0xFF)};
  return this->write_bytes(reg, data, 2);
}

void AD5593RComponent::setup() {
  ESP_LOGCONFIG(TAG, "Initializing AD5593R at I2C address 0x%02X...", this->address_);

  // 1. Software Reset
  if (!this->write_reg_16(AD5593R_REG_SW_RESET, 0x0AC5)) {
    ESP_LOGE(TAG, "Communication failed: AD5593R did not respond to software reset!");
    this->mark_failed();
    return;
  }
  delay(5);

  // 2. Power-down / Reference Control: Enable internal 2.5V reference (bit 9)
  if (!this->write_reg_16(AD5593R_REG_POWER_REF_CTRL, 0x0200)) {
    ESP_LOGE(TAG, "Failed to enable internal reference on AD5593R!");
    this->mark_failed();
    return;
  }
  delay(2);

  // 3. General-Purpose Control: ADC buffer enabled (bit 8), Gain 2x for ADC (bit 5) & DAC (bit 4)
  uint16_t gen_ctrl = 0x0100;
  if (this->gain_2x_) {
    gen_ctrl |= 0x0030;
  }
  if (!this->write_reg_16(AD5593R_REG_GEN_CTRL, gen_ctrl)) {
    ESP_LOGE(TAG, "Failed to configure General-Purpose Control register!");
    this->mark_failed();
    return;
  }

  // 4. Configure DAC pins
  if (this->dac_pin_mask_ != 0) {
    if (!this->write_reg_16(AD5593R_REG_DAC_CONFIG, this->dac_pin_mask_)) {
      ESP_LOGE(TAG, "Failed to configure DAC pins (mask: 0x%02X)!", this->dac_pin_mask_);
      this->mark_failed();
      return;
    }
    // Initialize active DAC outputs to 0V
    for (uint8_t ch = 0; ch < 8; ch++) {
      if (this->dac_pin_mask_ & (1 << ch)) {
        this->write_dac(ch, 0.0f);
      }
    }
  }

  // 5. Configure ADC pins
  if (this->adc_pin_mask_ != 0) {
    if (!this->write_reg_16(AD5593R_REG_ADC_CONFIG, this->adc_pin_mask_)) {
      ESP_LOGE(TAG, "Failed to configure ADC pins (mask: 0x%02X)!", this->adc_pin_mask_);
      this->mark_failed();
      return;
    }
  }

  // 6. Configure GPIO Outputs
  if (this->gpio_out_mask_ != 0) {
    if (!this->write_reg_16(AD5593R_REG_GPIO_OUT_CONFIG, this->gpio_out_mask_)) {
      ESP_LOGE(TAG, "Failed to configure GPIO outputs (mask: 0x%02X)!", this->gpio_out_mask_);
      this->mark_failed();
      return;
    }
    this->write_reg_16(AD5593R_REG_GPIO_OUT_DATA, this->gpio_out_state_);
  }

  // 7. Configure GPIO Inputs
  if (this->gpio_in_mask_ != 0) {
    if (!this->write_reg_16(AD5593R_REG_GPIO_IN_CONFIG, this->gpio_in_mask_)) {
      ESP_LOGE(TAG, "Failed to configure GPIO inputs (mask: 0x%02X)!", this->gpio_in_mask_);
      this->mark_failed();
      return;
    }
  }

  // 8. Configure Pull-down resistors
  if (!this->write_reg_16(AD5593R_REG_PULLDOWN, this->pulldown_mask_)) {
    ESP_LOGE(TAG, "Failed to configure pull-downs (mask: 0x%02X)!", this->pulldown_mask_);
    this->mark_failed();
    return;
  }

  ESP_LOGCONFIG(TAG, "AD5593R initialized successfully. Gain=%s (0-%.1fV)",
                this->gain_2x_ ? "2x" : "1x",
                this->gain_2x_ ? (this->reference_voltage_ * 2.0f) : this->reference_voltage_);
}

void AD5593RComponent::dump_config() {
  ESP_LOGCONFIG(TAG, "AD5593R:");
  LOG_I2C_DEVICE(this);
  if (this->is_failed()) {
    ESP_LOGE(TAG, "  Communication with AD5593R failed!");
    return;
  }
  ESP_LOGCONFIG(TAG, "  Reference Voltage: %.2f V", this->reference_voltage_);
  ESP_LOGCONFIG(TAG, "  Gain Mode: %s (Max: %.2f V)",
                this->gain_2x_ ? "2x" : "1x",
                this->gain_2x_ ? (this->reference_voltage_ * 2.0f) : this->reference_voltage_);
  ESP_LOGCONFIG(TAG, "  DAC Pins Mask: 0x%02X", this->dac_pin_mask_);
  ESP_LOGCONFIG(TAG, "  ADC Pins Mask: 0x%02X", this->adc_pin_mask_);
  ESP_LOGCONFIG(TAG, "  GPIO Outputs Mask: 0x%02X", this->gpio_out_mask_);
  ESP_LOGCONFIG(TAG, "  GPIO Inputs Mask: 0x%02X", this->gpio_in_mask_);
  ESP_LOGCONFIG(TAG, "  Pull-Down Mask: 0x%02X", this->pulldown_mask_);
}

void AD5593RComponent::loop() {
#ifdef USE_BINARY_SENSOR
  if (this->is_failed() || this->binary_sensors_.empty()) {
    return;
  }

  uint32_t now = millis();
  if (now - this->last_gpio_read_ < 30) {
    return;
  }
  this->last_gpio_read_ = now;

  uint8_t pin_states = 0;
  if (!this->read_gpio(pin_states)) {
    return;
  }

  for (auto *bs : this->binary_sensors_) {
    bool state = (pin_states & (1 << bs->get_channel())) != 0;
    if (!bs->has_state() || bs->state != state) {
      bs->publish_state(state);
    }
  }
#endif
}

#ifdef USE_OUTPUT
void AD5593RComponent::register_dac_channel(AD5593RChannel *channel) {
  if (channel->get_channel() < 8) {
    this->dac_pin_mask_ |= (1 << channel->get_channel());
  }
}
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

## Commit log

2026-09-17 Enhance README with detailed hardware specs and safety info
    Expanded project documentation to include detailed hardware specifications and safety guidelines for three board versions: Full Version, Light Version, and Expansion Board.
2026-09-17 light housing
    [esp_home_light_housing.step]
2026-09-17 files change
    [ESP_HOME_ligh.brd, ESP_HOME_ligh.sch, ESP_NOW_uni_FULL.brd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]

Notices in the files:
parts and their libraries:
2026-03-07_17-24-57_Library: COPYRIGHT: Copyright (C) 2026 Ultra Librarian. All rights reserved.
